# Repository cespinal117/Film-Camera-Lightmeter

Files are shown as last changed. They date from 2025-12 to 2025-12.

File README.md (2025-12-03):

# Film-Camera-Lightmeter
A PCB I designed to integrate a light meter onto my film camera.  
My inspiration for this was when I got my first film camera, a Cannon AE-1, I noticed the built-in light-meter was broken.  
For most of my time, I have been using my phone with a light-meter app to adjust my camera settings but that got annoying quick. 
Since I wanted to practice more PCB design, I figured the best way to get practice in and solve my issue is to make my own light meter and manufacture a PCB for it.

## PCB Features
 - Raspberry Pi Pico MCU
 - VEML7700-TR Ambient Light Sensor
 - Lipo battery charging circuit
 - Button control inputs
 - Automatic switching between USB power & Battery power
 - Static Discharge protection

## PCB Design

The PCB is a 2-layer board to minimize cost.  

It uses a Raspberry Pi Pico MCU as it was a relatively new board I was trying to learn to use. 
To power it, you can supply either USB-C for development, or a 3.7V Lipo battery.

It is still a WIP and I hope to have it manufactured soon.

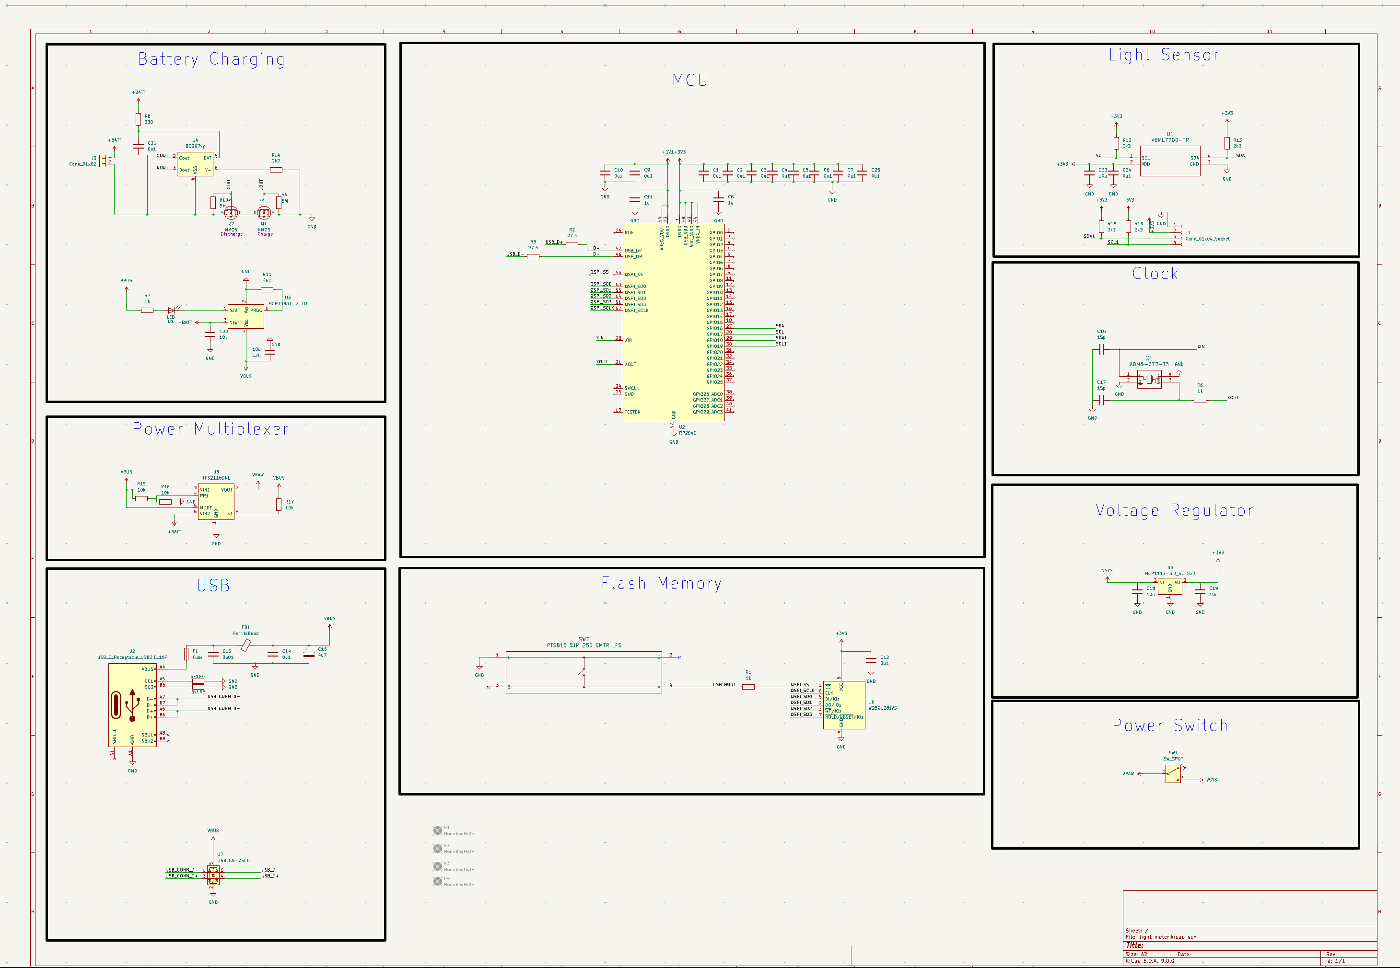
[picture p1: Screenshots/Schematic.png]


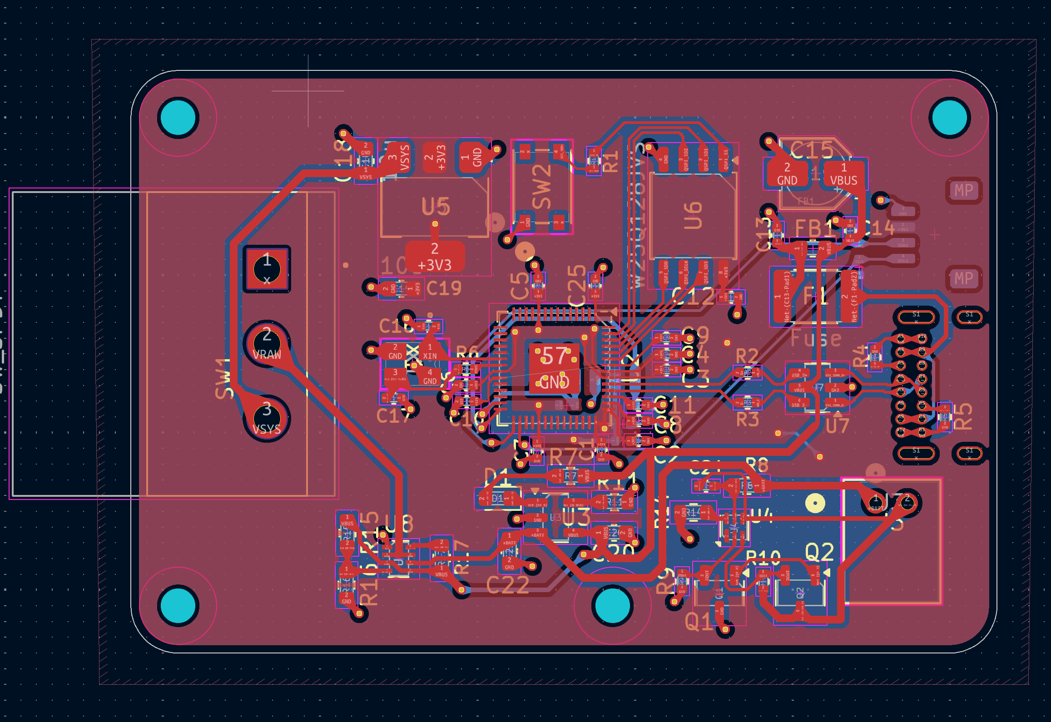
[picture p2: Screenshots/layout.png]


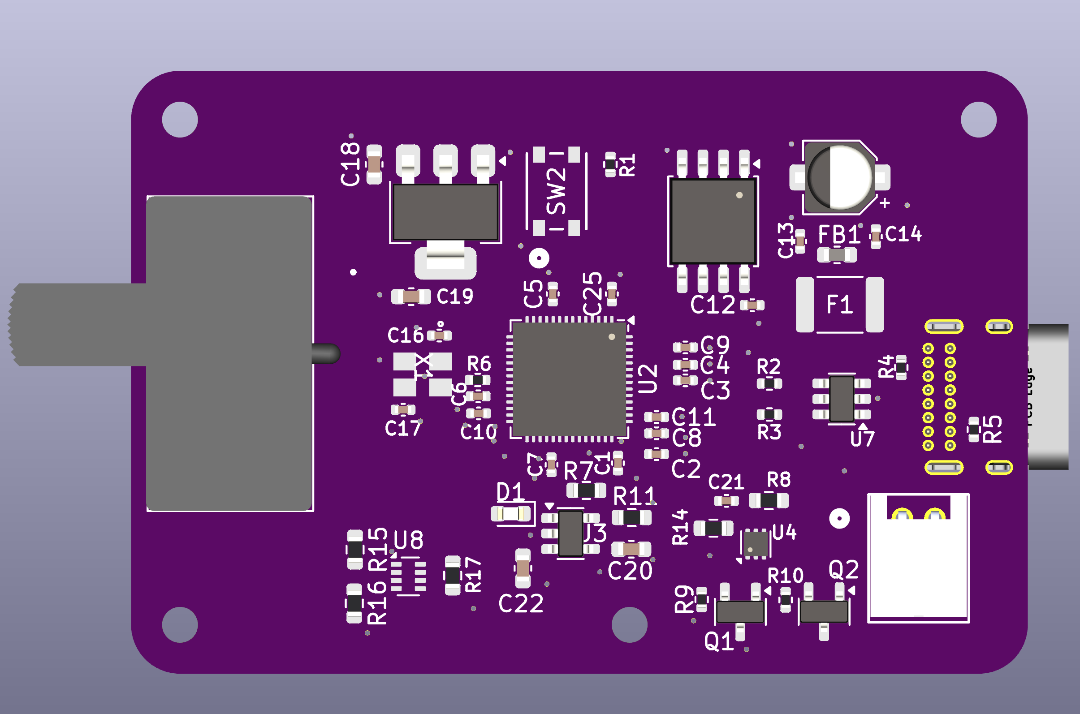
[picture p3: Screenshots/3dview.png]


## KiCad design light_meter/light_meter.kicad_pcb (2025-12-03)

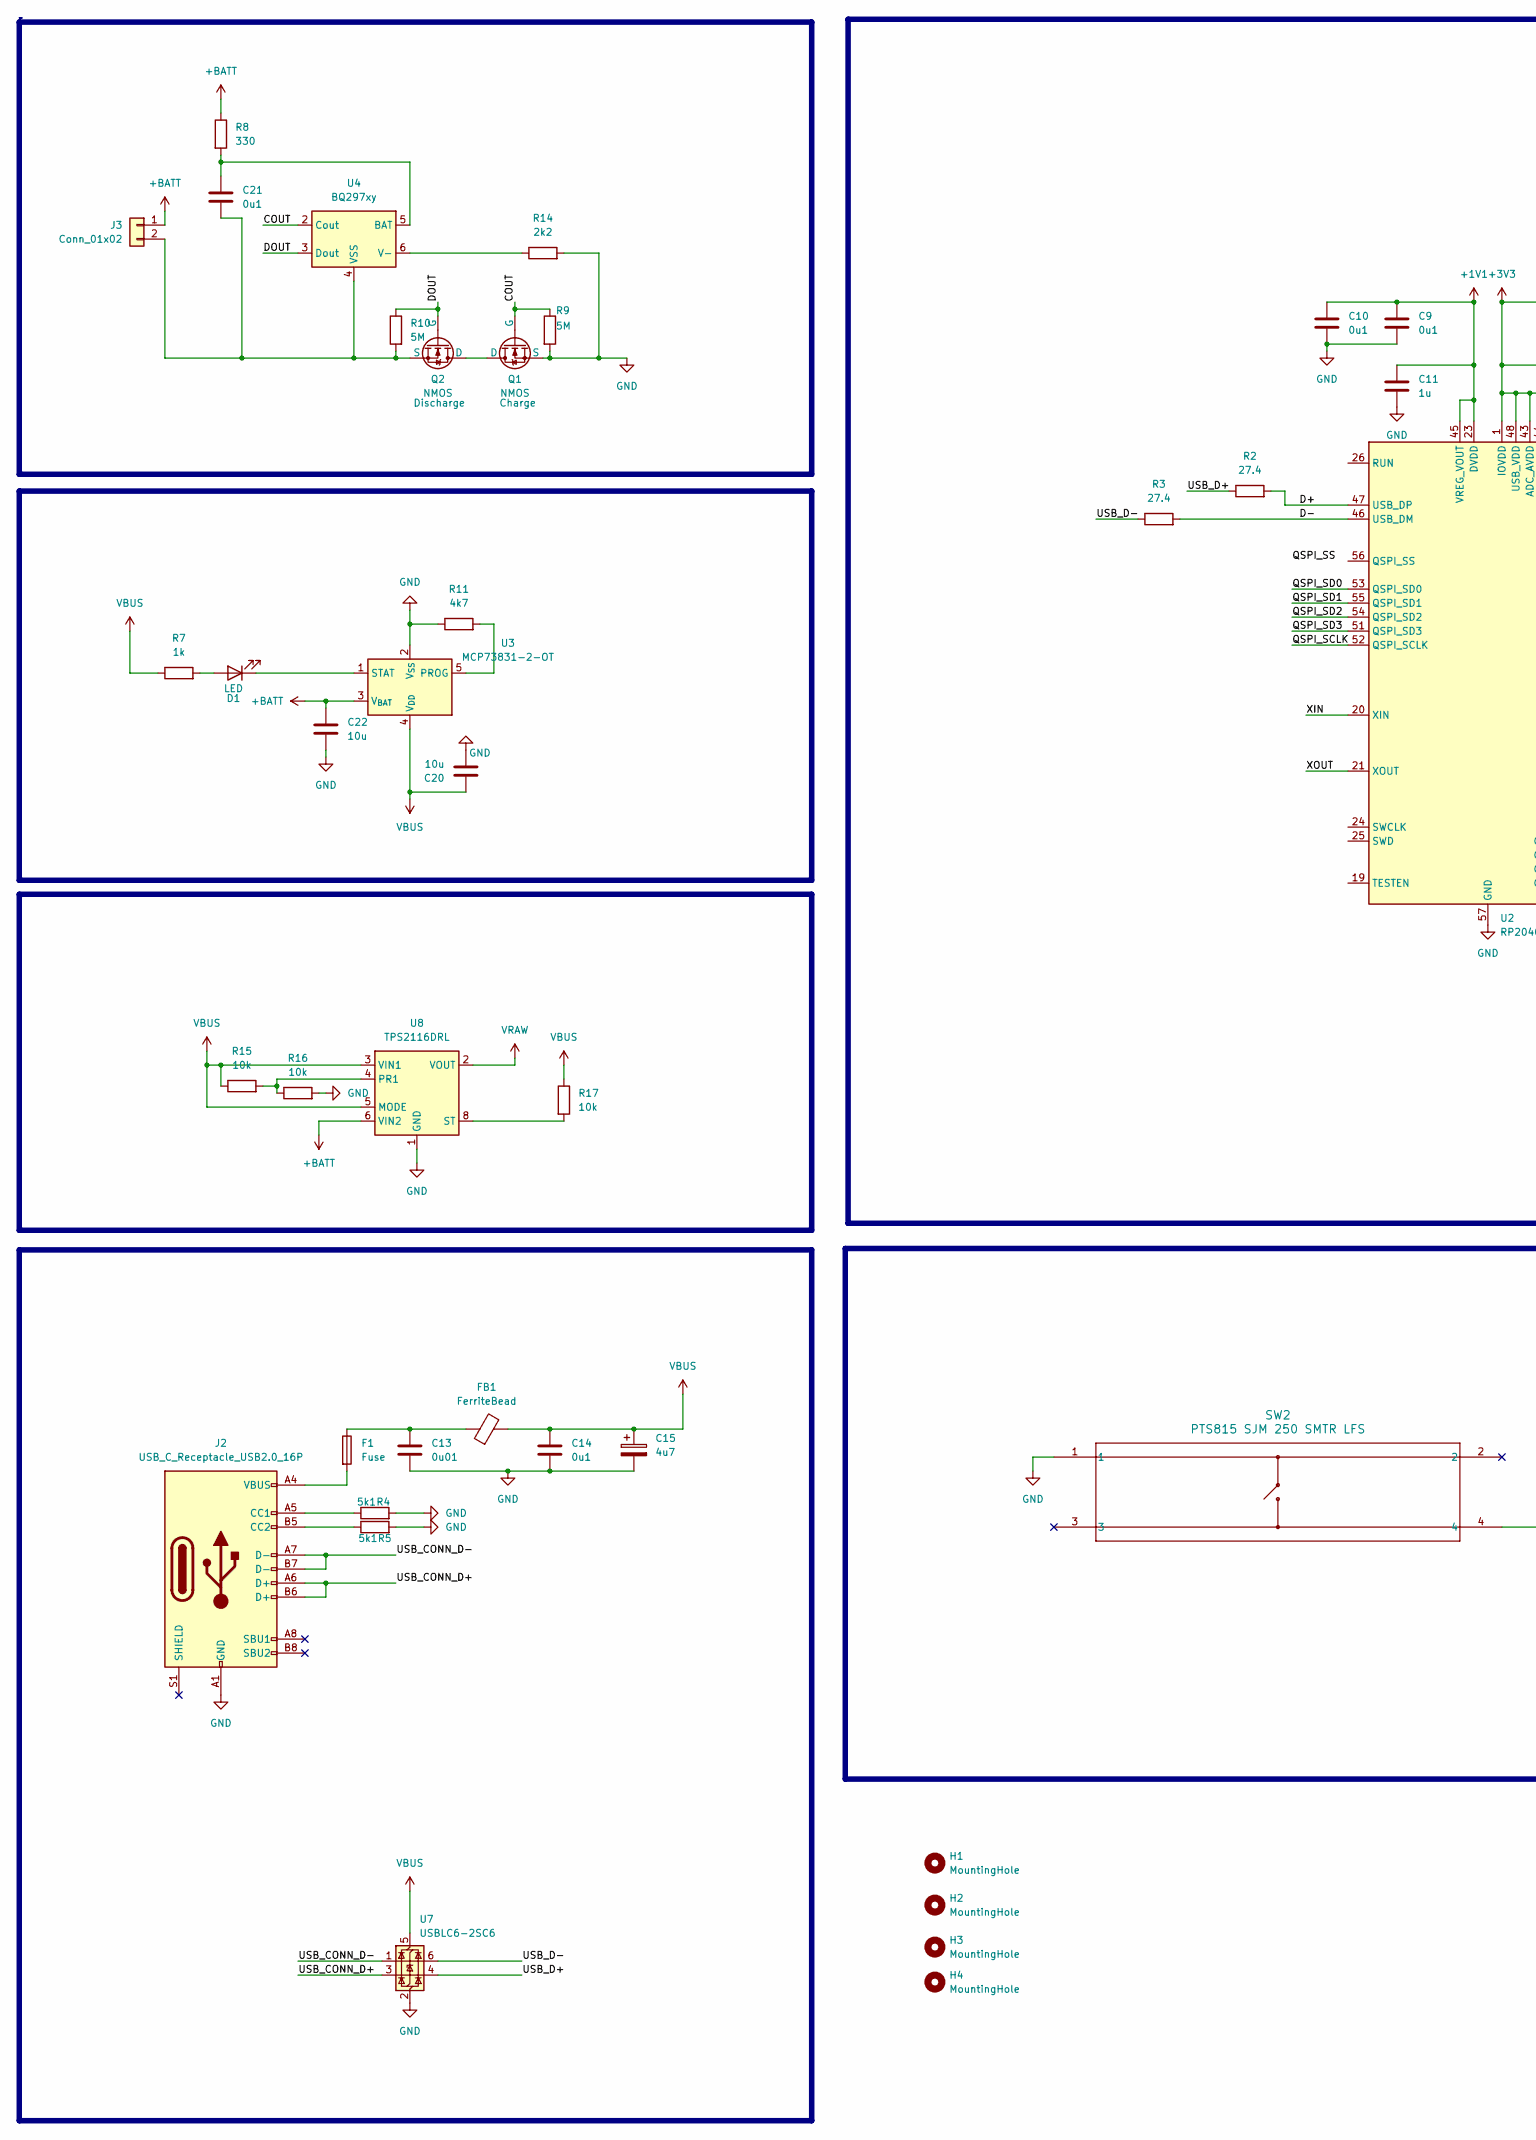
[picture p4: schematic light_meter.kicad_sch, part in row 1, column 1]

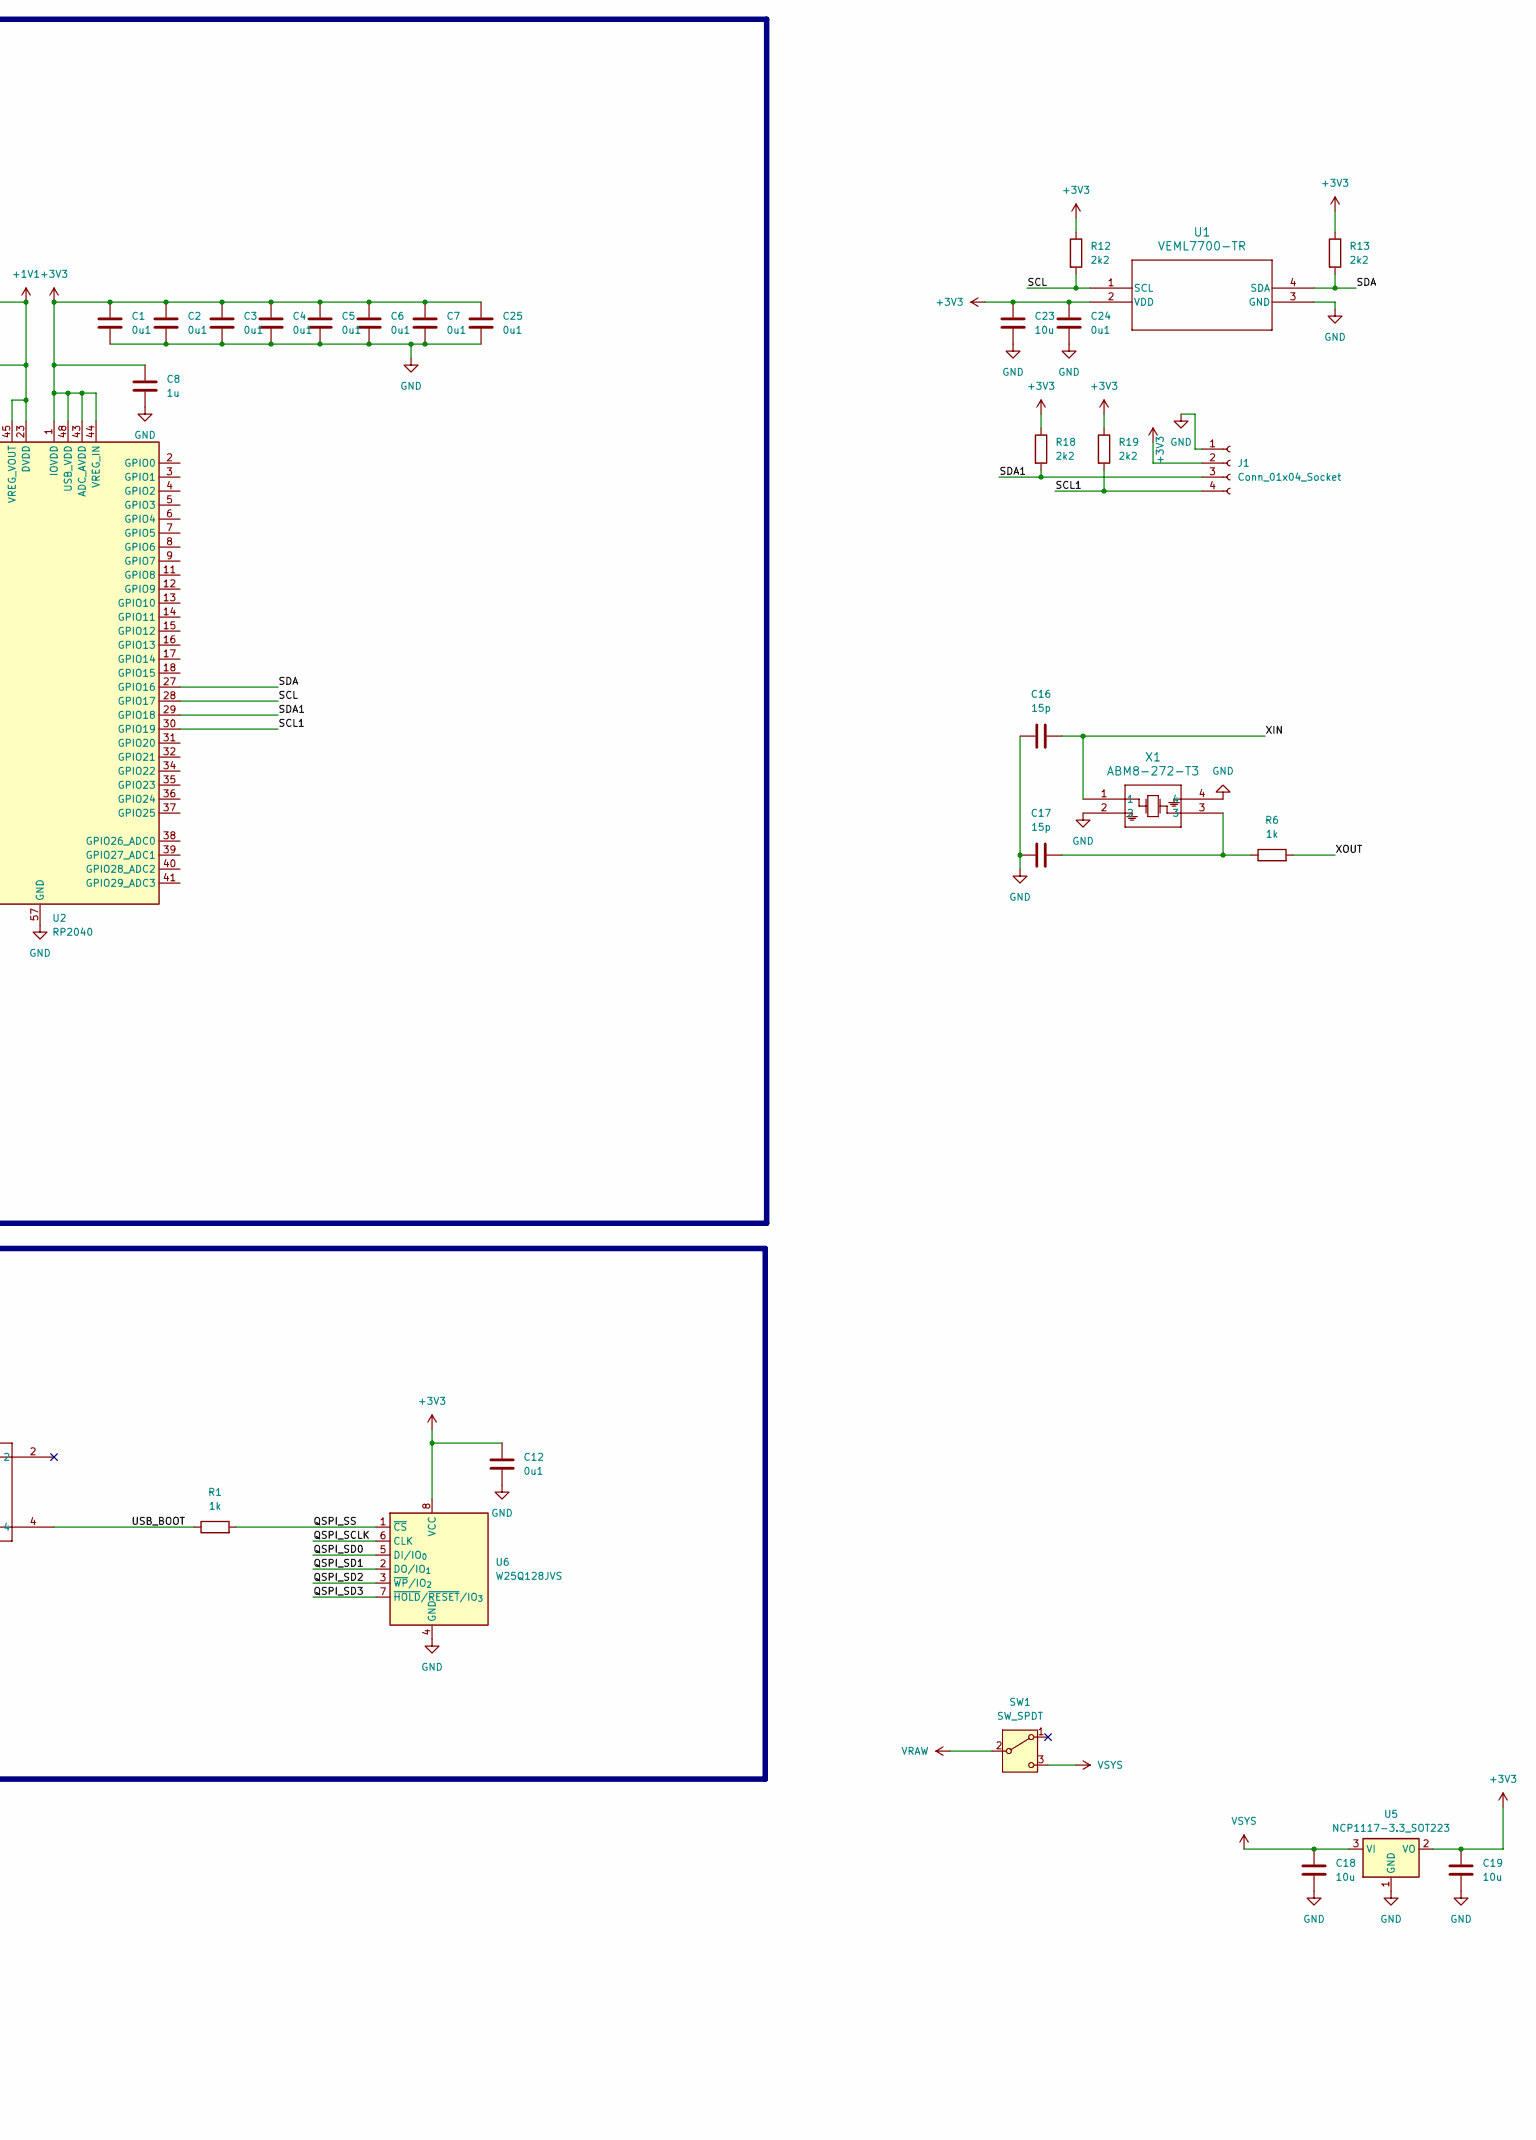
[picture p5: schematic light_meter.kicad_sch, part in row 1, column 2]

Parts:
C1, C2, C3, C4, C5, C6, C7, C9, C10, C12, C14, C21, C24, C25: 0u1; C_0402_1005Metric
C8, C11: 1u; C_0402_1005Metric
C13: 0u01; C_0402_1005Metric
C15: 4u7; CP_Elec_4x5.7
C16, C17: 15p; C_0402_1005Metric
C18, C19, C20, C22: 10u; C_0603_1608Metric
C23: 10u; C_0402_1005Metric
D1: LED; LED_0603_1608Metric
F1: Fuse; Fuse_1812_4532Metric
FB1: FerriteBead; L_0603_1608Metric
H1, H2, H3, H4: MountingHole; MountingHole_2.2mm_M2
J1: Conn_01x04_Socket; JST_SH_SM04B-SRSS-TB_1x04-1MP_P1.00mm_Horizontal
J2: USB_C_Receptacle_USB2.0_16P; USB_C_Receptacle_GCT_USB4085; Part Number 2073-USB4085-GF-ATR-ND
J3: Conn_01x02; CONN_S2B-PH-K-S_JST; part number 455-1719-ND
Q1, Q2: NMOS; SOT-23-3
R1, R6: 1k; R_0402_1005Metric
R2, R3: 27.4; R_0402_1005Metric
R4, R5: 5k1; R_0402_1005Metric
R7: 1k; R_0603_1608Metric
R8: 330; R_0603_1608Metric
R9, R10: 5M; R_0402_1005Metric
R11: 4k7; R_0603_1608Metric
R12, R13, R18, R19: 2k2; R_0402_1005Metric
R14: 2k2; R_0603_1608Metric
R15, R16, R17: 10k; R_0603_1608Metric
SW1: SW_SPDT; SW_L102021ML04Q; digikey CKC5102-ND
SW2: PTS815 SJM 250 SMTR LFS; SW4_PTS815 SJM 250 SMTR LFS_CNK
U1: VEML7700-TR
U2: RP2040; QFN-56-1EP_7x7mm_P0.4mm_EP3.2x3.2mm
U3: MCP73831-2-OT; SOT-23-5
U4: BQ297xy; WSON-6_1.5x1.5mm_P0.5mm
U5: NCP1117-3.3_SOT223; SOT-223-3_TabPin2
U6: W25Q128JVS; SOIC-8_5.3x5.3mm_P1.27mm
U7: USBLC6-2SC6; SOT-23-6
U8: TPS2116DRL; SOT-583-8
X1: ABM8-272-T3; ABM8-272-T3_ABR

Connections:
+1V1: C9.1, C10.1, C11.1, U2.23 (DVDD), U2.45 (VREG_VOUT), U2.50 (DVDD)
+3V3: C1.1, C2.1, C3.1, C4.1, C5.1, C6.1, C7.1, C8.1, C12.1, C19.1, C23.1, C24.1, C25.1, J1.2, R12.1, R13.1, R18.1, R19.1, U1.2 (VDD), U2.1 (IOVDD), U2.10 (IOVDD), U2.22 (IOVDD), U2.33 (IOVDD), U2.42 (IOVDD), U2.43 (ADC_AVDD), U2.44 (VREG_IN), U2.48 (USB_VDD), U2.49 (IOVDD), U5.2 (VO), U6.8 (VCC)
+BATT: C22.1, J3.1, R8.1, U3.3 (V_{BAT}), U8.6 (VIN2)
/COUT: Q1.2 (G), R9.1, U4.2 (Cout)
/D+: R2.2, U2.47 (USB_DP)
/D-: R3.2, U2.46 (USB_DM)
/DOUT: Q2.2 (G), R10.1, U4.3 (Dout)
/QSPI_SCLK: U2.52 (QSPI_SCLK), U6.6 (CLK)
/QSPI_SD0: U2.53 (QSPI_SD0), U6.5 (DI/IO_{0})
/QSPI_SD1: U2.55 (QSPI_SD1), U6.2 (DO/IO_{1})
/QSPI_SD2: U2.54 (QSPI_SD2), U6.3 (~WP/IO_{2})
/QSPI_SD3: U2.51 (QSPI_SD3), U6.7 (~HOLD/~RESET/IO_{3})
/QSPI_SS: R1.2, U6.1 (~CS)
/SCL: R12.2, U1.1 (SCL), U2.28 (GPIO17)
/SCL1: J1.4, R19.2, U2.30 (GPIO19)
/SDA: R13.2, U1.4 (SDA), U2.27 (GPIO16)
/SDA1: J1.3, R18.2, U2.29 (GPIO18)
/USB_BOOT: R1.1, SW2.4
/USB_CONN_D+: J2.A6 (D+), J2.B6 (D+), U7.3 (I/O2)
/USB_CONN_D-: J2.A7 (D-), J2.B7 (D-), U7.1 (I/O1)
/USB_D+: R2.1, U7.4 (I/O2)
/USB_D-: R3.1, U7.6 (I/O1)
/XIN: C16.2, U2.20 (XIN), X1.1
/XOUT: R6.2, U2.21 (XOUT)
GND: C1.2, C2.2, C3.2, C4.2, C5.2, C6.2, C7.2, C8.2, C9.2, C10.2, C11.2, C12.2, C13.2, C14.2, C15.2, C16.1, C17.1, C18.2, C19.2, C20.2, C22.2, C23.2, C24.2, C25.2, J1.1, J2.A1 (GND), J2.A12 (GND), J2.B1 (GND), J2.B12 (GND), Q1.3 (S), R4.2, R5.2, R9.2, R11.1, R14.2, R16.2, SW2.1, U1.3 (GND), U2.57 (GND), U3.2 (V_{SS}), U5.1 (GND), U6.4 (GND), U7.2 (GND), U8.1 (GND), X1.2, X1.4
unnamed: C13.1, F1.1, FB1.1
unnamed: C17.2, R6.1, X1.3
unnamed: D1.2 (A), R7.2
unnamed: D1.1 (K), U3.1 (STAT)
unnamed: F1.2, J2.A4 (VBUS), J2.A9 (VBUS), J2.B4 (VBUS), J2.B9 (VBUS)
unnamed: J2.A5 (CC1), R4.1
unnamed: J2.B5 (CC2), R5.1
unnamed: C21.2, J3.2, Q2.3 (S), R10.2, U4.4 (VSS)
unnamed: Q1.1 (D), Q2.1 (D)
unnamed: R11.2, U3.5 (PROG)
unnamed: C21.1, R8.2, U4.5 (BAT)
unnamed: R14.1, U4.6 (V-)
unnamed: R15.2, R16.1, U8.4 (PR1)
unnamed: R17.2, U8.8 (ST)
VBUS: C14.1, C15.1, C20.1, FB1.2, R7.1, R15.1, R17.1, U3.4 (V_{DD}), U7.5 (VBUS), U8.3 (VIN1), U8.5 (MODE)
VRAW: SW1.2 (B), U8.2 (VOUT), U8.7 (VOUT)
VSYS: C18.1, SW1.3 (C), U5.3 (VI)

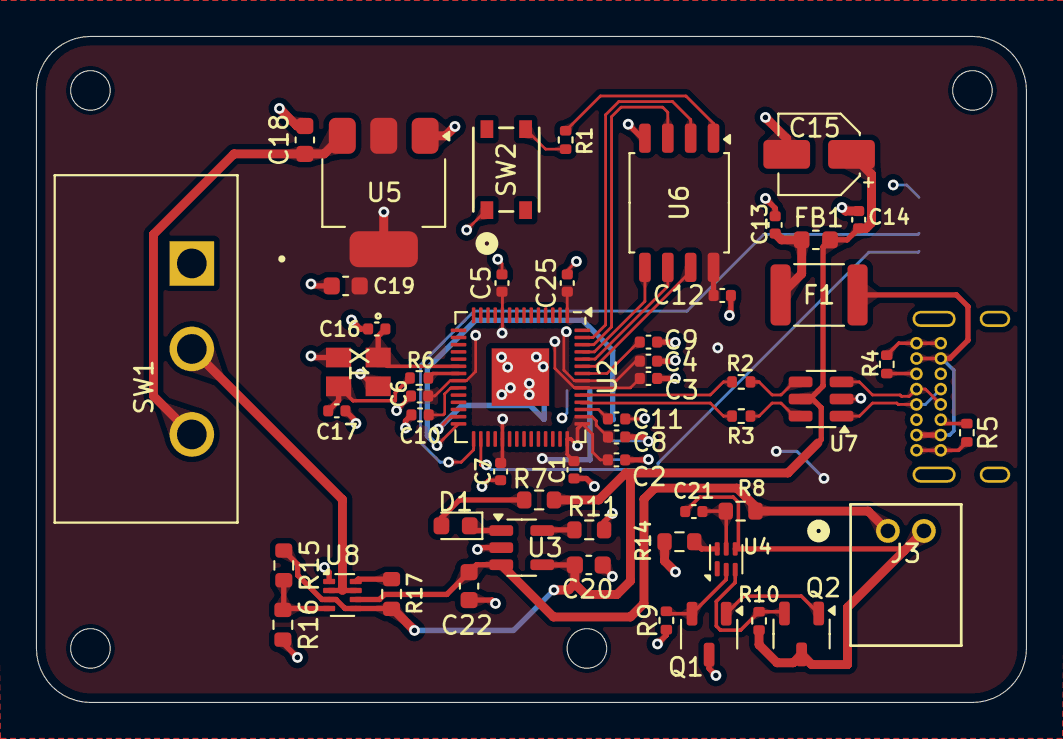
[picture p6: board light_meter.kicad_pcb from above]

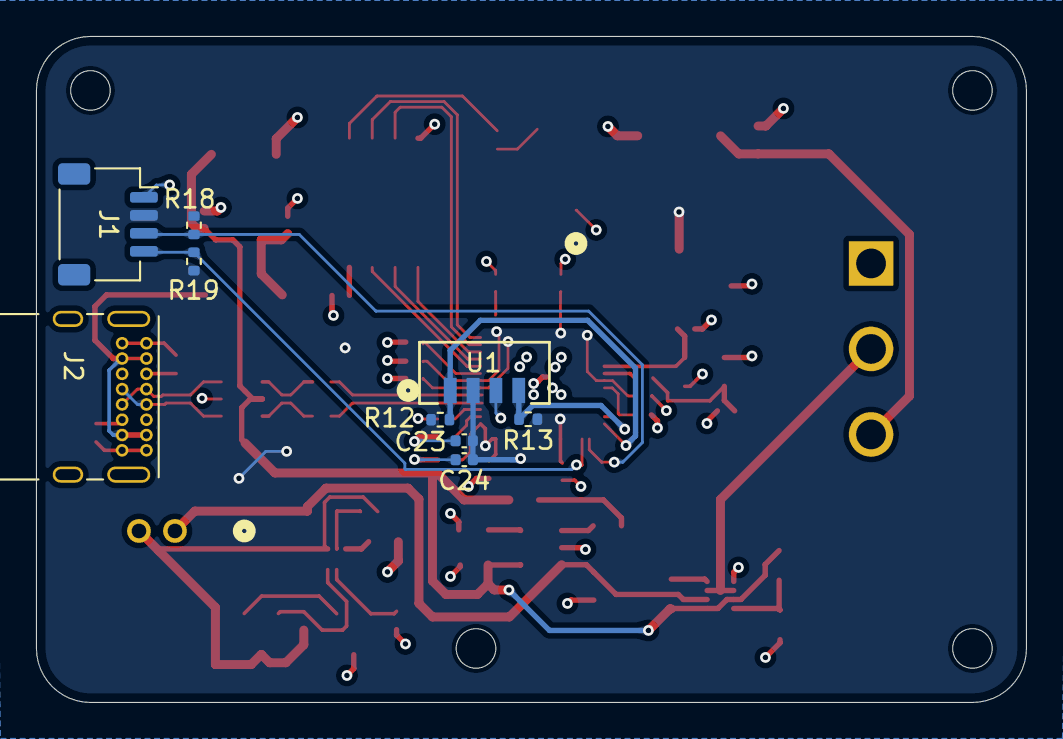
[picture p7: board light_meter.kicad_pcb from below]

Board: 4 copper layers, 55.0 x 37.0 mm, 67 parts (9 on the bottom side), 42 nets.
